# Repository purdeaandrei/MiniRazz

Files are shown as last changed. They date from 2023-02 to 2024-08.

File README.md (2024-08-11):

# MiniRazz - open hardware controller replacement for the Mini M keyboard.

This is a replacement keyboard controller, for the Unicomp Mini M
keyboard, this is an independent community project that is not endorsed by
Unicomp, and it is not related to any official controller sold by them.

Licensed under CERN-OHL-P v2 or later

## Images

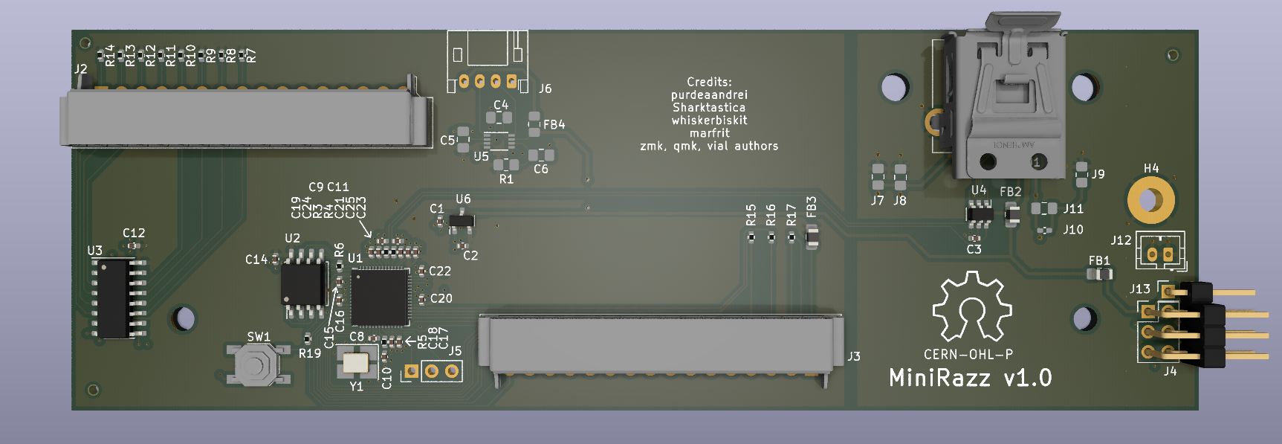
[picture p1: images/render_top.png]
Top of the controller board

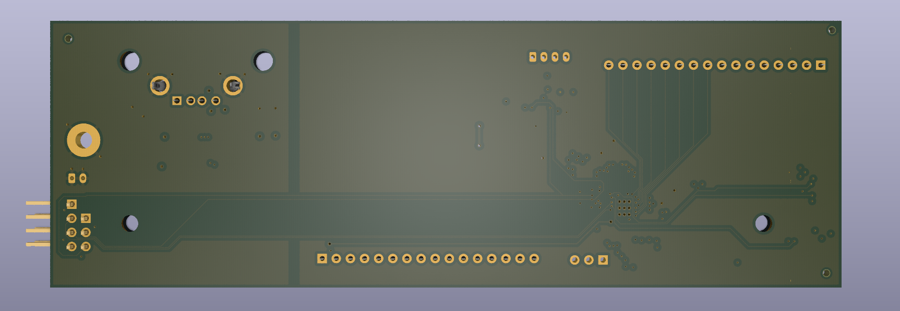
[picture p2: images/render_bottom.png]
Bottom of the controller board


## How to order from JLCPCB:
1. Go to http://jlcpcb.com , sign in to your account (create one if you don't have one)
2. Click Order Now, click Add gerber file
3. Upload the .zip file from the "order" subfolder.
4. Wait for the gerbers to be processed.
5. Check that it correctly detected 4-layerboard.
6. Select PCB Qty you wish to build
7. Specify Layer Sequence, click Yes, And select L1=F_Cu L2=In1_Cu L3=In2_Cu L4=B_Cu
8. Set "Remove Order Number" to "Specify a location"
9. Scroll down, turn on the "SMT Assembly" option, turn it on
10. Select "PCBA Type" = "Economic"
11. Select "Assembly Side" = "Top Side"
12. Select "Tooling holes" = "Added by Customer"
13. Click "I agree to the Terms and Conditions..."
14. Click "Next" on the right side
15. Click "Next" on the right side
16. Click "Add BOM File", upload the "*_bom_jlc.csv" file from the "order" subfolder.
17. Click "Add CPL File", upload the "*_cpl_jlc.csv" file from the "order" subfolder.
18. Click "Process BPM & CPL"
19. Take a look at what parts are available. At the time of writing J2/J3 triomate connectors were only available if pre-ordered (at a higher cost than ordering from DigiKey).
    You may be able to optimize cost by choosing to solder certain parts yourself, through-hole parts being the most likely candidate. (Please see the following section)
20. Click "Next", you will also have to click "Do Not Place" if some components are missing.
21. Check the rotation of components. JLCPCB may change default rotation in their component libraries at any time, and also position and rotation of the triomates has not been verified.
    - Check that component pins line up correctly with pads
    - Check that components which have polarity (usually marked with a dot) are oriented towards an assimetric marking on the silkscreen (for example for the memory and the io expander there's an extra line, while for the RP2040 there's a missing corner line to mark pin 1)
22. Click "Next"
23. Select Product Description: Office Appliance.../Keyboard...
24. Save to Cart, Check Out.

Cost analysis at the time of writing (2024 Aug 11):

| Qty | JLCPCB (USD) | JLC shipping est. (USD) | Digikey Triomates (USD) | Digikey shipping est. (USD) | VAT (19%) USD | Total (USD) | Coast per Board (USD) |
|-----|---|---|---|---|---|---|---|
| 5 | 84.34 | 23.80 | 14.66 | 30 | 29.03 | 181.83 | 36.37 |
| 10  |  106.13 | 29.80 | 29.32 | 30 | 37.10 | 232.35 | 23.24 |
| 15  |  130.10 | 55.54 | 43.76 | 30 | 49.29 | 308.69 | 20.58 |
| 20  |  154.18 | 57.74 | 58.35 | 30 | 57.05 | 357.32 | 17.87 |

## Components of this design that may have to be ordered separately:
- 2 pcs of 16-pin 90-degree triomate connectors / board:
   - Part number: `6-520314-6` (TE Connectivity AMP Connectors)
   - [Digikey](https://www.digikey.com/en/products/detail/te-connectivity-amp-connectors/6-520314-6/1153749)
   - If the 90-degree connectors are not in stock, then you may also be able to get away with vertical ones (part number `6-520315-6`)
      - This has not yet been tested for fit in the keyboard.
   - JLCPCB now has it in its library, however it's not in stock.
     - You can pre-order it, and then have them assemble it, however it may not make financial sense (current costs are higher than from digikey, and you have to order 5 pcs extra for attrition.)
       - If you decide to have JLCPCB assemble this component, it is present in the bom/cpl files, but make sure the connector position/rotations are connect. I could not verify because they weren't in stock at the time I last checked.

## Other through hole components that may make sense to buy separately and to solder yourself:
- USB connector with locking tab
   - Part number: `LUSBA11100` (AMPHENOL COMMUNICATIONS SOLUTIONS)
   - [Digikey](https://www.digikey.com/en/products/detail/amphenol-cs-commercial-products/LUSBA11100/1956311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)
   - [Farnell](https://ro.farnell.com/amphenol-icc-commercial-products/lusba11100/usb-conn-2-0-type-a-receptacle/dp/2708971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)
- Optional 90 degree headers for solenoid support. You can use one of two options:
   - An 1x4 90-degree header: (recommended)
      - You will need to use single jumper wires to connect the solenoid driver, (or need to crimp a custom cable with dupont connectors)
   - A 2x3 90-degree header: (not recommended)
      - This may not fit well in the space available, and you may need to add tape to isolate the bottom of the backplate.

## Firmware

VIAL-QMK and ZMK firmwares are available, (plain QMK upstreaming will also be attempted).

### VIAL Firmware
Download from here:
https://github.com/purdeaandrei/vial-qmk-minirazz/releases

Use `unicomp_mini_m_minirazz_vial.uf2` or `unicomp_mini_m_minirazz_vial_debug.uf2`

### ZMK Firmware
The ZMK firmware can be downloaded by clicking Releases here: https://github.com/purdeaandrei/minirazz-zmk-config
The keymap can be customized by forking this repository, and editing the keymap. The firmware will be automatically rebuilt by github, and will be available on the "Actions" tab.
If you want to keep your keymap secret, you can copy the content of this repository into a private github repository.

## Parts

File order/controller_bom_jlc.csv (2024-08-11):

Comment | Designator | Footprint | LCSC Part Number
1uF | C1,C2,C21,C25 | C_0402_1005Metric | C52923
100nF | C3,C12,C14,C15,C16,C17,C18,C19,C20,C22,C23,C24 | C_0402_1005Metric | C1525
30pF | C8,C10 | C_0402_1005Metric | C1570
43pF | C9,C11 | C_0402_1005Metric | C415393
Ferrite_Bead | FB1,FB2,FB3 | L_0805_2012Metric_Pad1.15x1.40mm_HandSolder | C1015
USB_A | J1 | LUSB_A111_00 | C3197751
Conn_01x16 | J2,J3 | TE_connectivity_AMP_6-520314-6 | C7191217
3.3V IO EXPANSION HEADER | J4 | PinHeader_2x03_P2.54mm_Vertical_3dhorizontal | C706867
27.4 | R3,R4 | R_0402_1005Metric | C284479
1k | R5,R19 | R_0402_1005Metric | C11702
10k | R6 | R_0402_1005Metric | C25744
68k | R7,R8,R9,R10,R11,R12,R13,R14 | R_0402_1005Metric | C36871
196 | R15,R16,R17 | R_0402_1005Metric | C270631
SW_Push | SW1 | switch_K2-1187SQ-A4SW-06 | C92584
RP2040 | U1 | QFN-56-1EP_7x7mm_P0.4mm_EP3.2x3.2mm | C2040
W25Q16JV | U2 | SOIC-8_5.275x5.275mm_P1.27mm | C82317
74HC165 | U3 | SOIC-16_3.9x9.9mm_P1.27mm | C5613
USBLC6-2SC6 | U4 | SOT-23-6 | C2827654
XC6206P332MR | U6 | SOT-23 | C5446
12MHz | Y1 | Crystal_SMD_3225-4Pin_3.2x2.5mm_HandSoldering | C9002

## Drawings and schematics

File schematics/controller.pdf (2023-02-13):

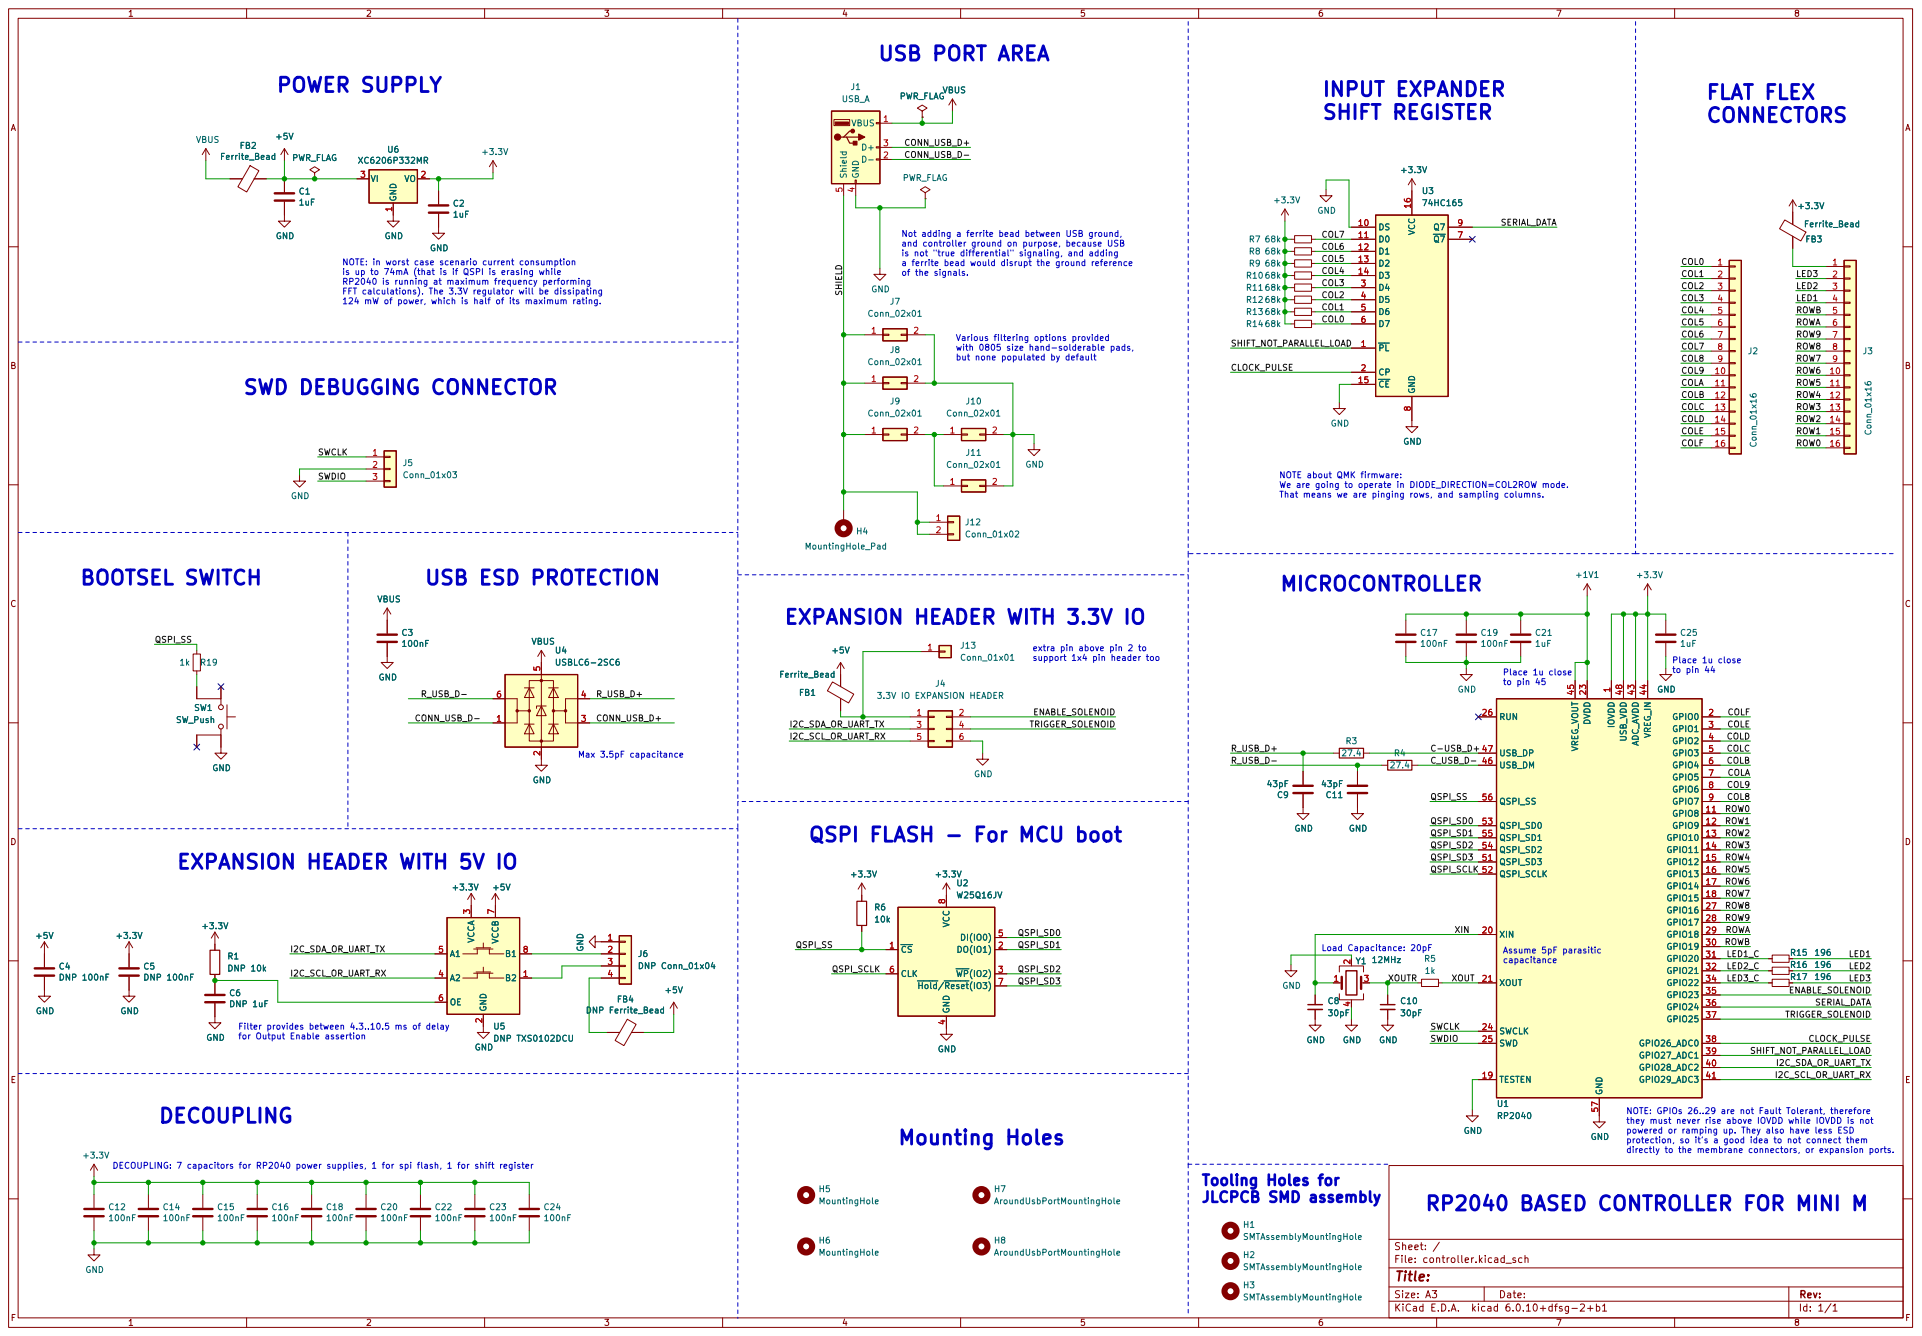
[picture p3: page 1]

1 VO 2 VI 3 U6 XC6206P332MR GND GND
PWR_FLAG

1 VO 2 VI 3 VBUS GND

Not adding a ferrite bead between USB ground,
and controller ground on purpose, because USB
is not "true differential" signaling, and adding
a ferrite bead would disrupt the ground reference
of the signals.
J12 Conn_01x02 GND

NOTE: in worst case scenario current consumption
is up to 74mA (that is if QSPI is erasing while
RP2040 is running at maximum frequency performing
FFT calculations). The 3.3V regulator will be dissipating
124 mW of power, which is half of its maximum rating.

Various filtering options provided
with 0805 size hand-solderable pads,
but none populated by default
GND

to pin 45 NOTE about QMK firmware: We are going to operate in DIODE_DIRECTION=COL2ROW mode.

That means we are pinging rows, and sampling columns.

EXPANSION HEADER WITH 3.3V IO

extra pin above pin 2 to

QSPI FLASH - For MCU boot
H5MountingHole +3.3VR6

EXPANSION HEADER WITH 5V IO

4 DI(IO0) 5 CLK 6 ~{Hold}/~{Reset}(IO3)7 VCC

Filter provides between 4.3..10.5 ms of delay

they must never rise above IOVDD while IOVDD is not
powered or ramping up. They also have less ESD
protection, so it's a good idea to not connect them
directly to the membrane connectors, or expansion ports.

DECOUPLING: 7 capacitors for RP2040 power supplies, 1 for spi flash, 1 for shift register

RP2040 BASED CONTROLLER FOR MINI M

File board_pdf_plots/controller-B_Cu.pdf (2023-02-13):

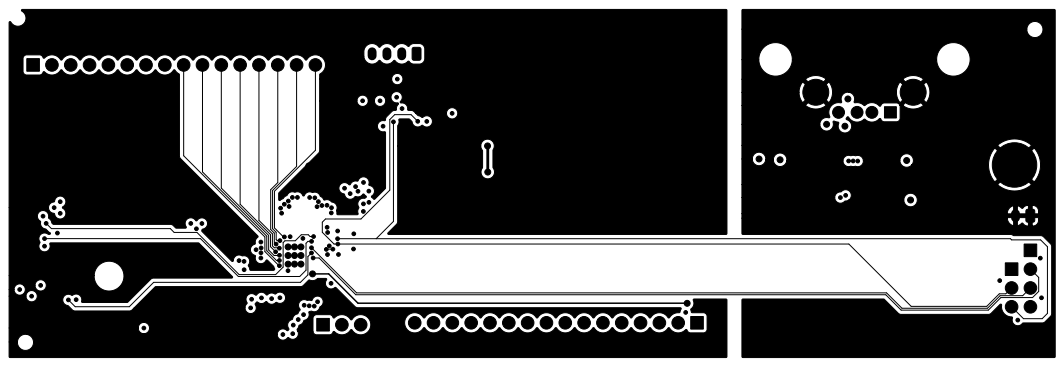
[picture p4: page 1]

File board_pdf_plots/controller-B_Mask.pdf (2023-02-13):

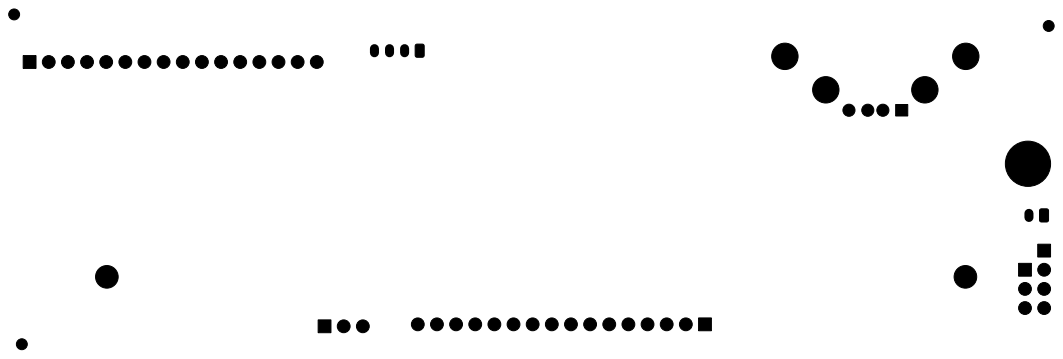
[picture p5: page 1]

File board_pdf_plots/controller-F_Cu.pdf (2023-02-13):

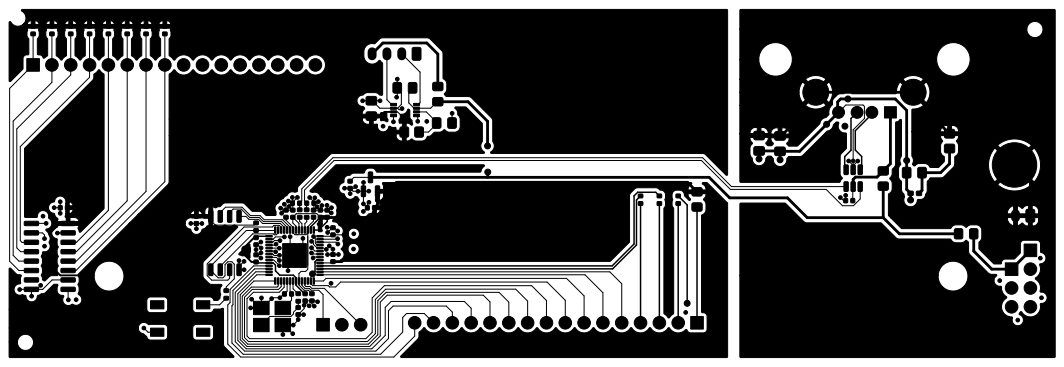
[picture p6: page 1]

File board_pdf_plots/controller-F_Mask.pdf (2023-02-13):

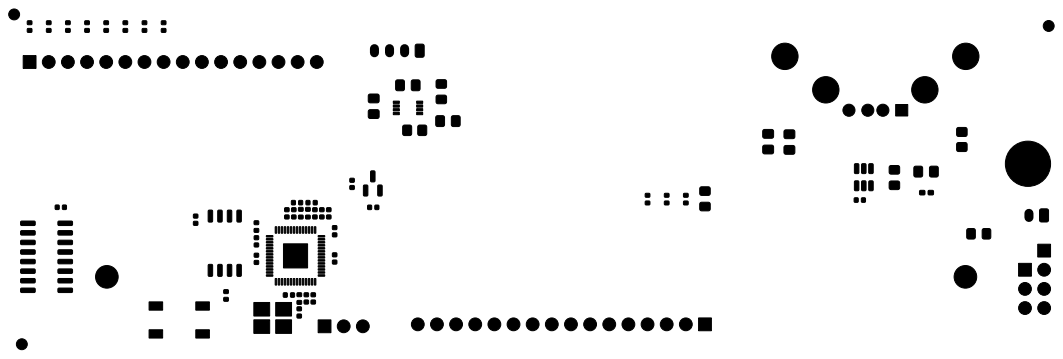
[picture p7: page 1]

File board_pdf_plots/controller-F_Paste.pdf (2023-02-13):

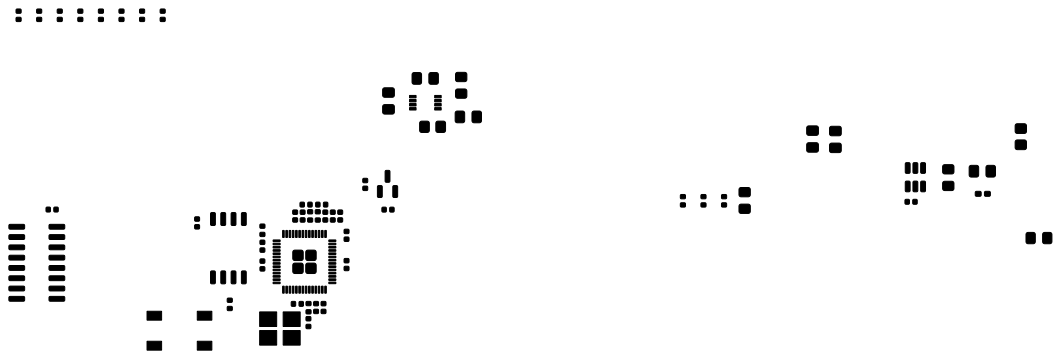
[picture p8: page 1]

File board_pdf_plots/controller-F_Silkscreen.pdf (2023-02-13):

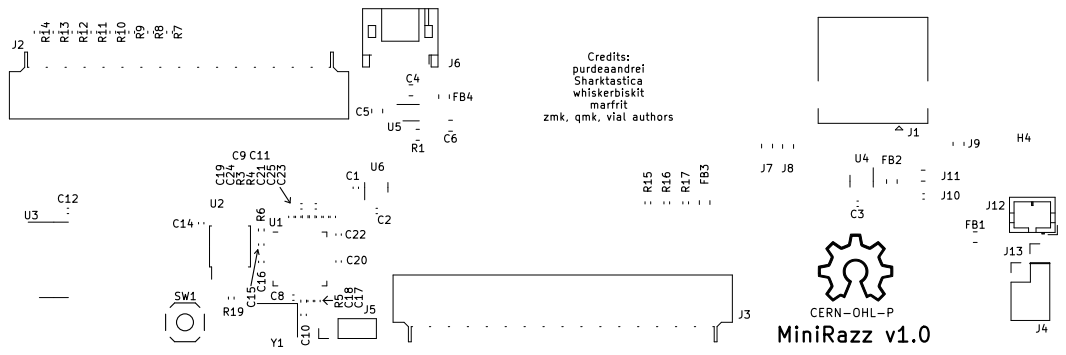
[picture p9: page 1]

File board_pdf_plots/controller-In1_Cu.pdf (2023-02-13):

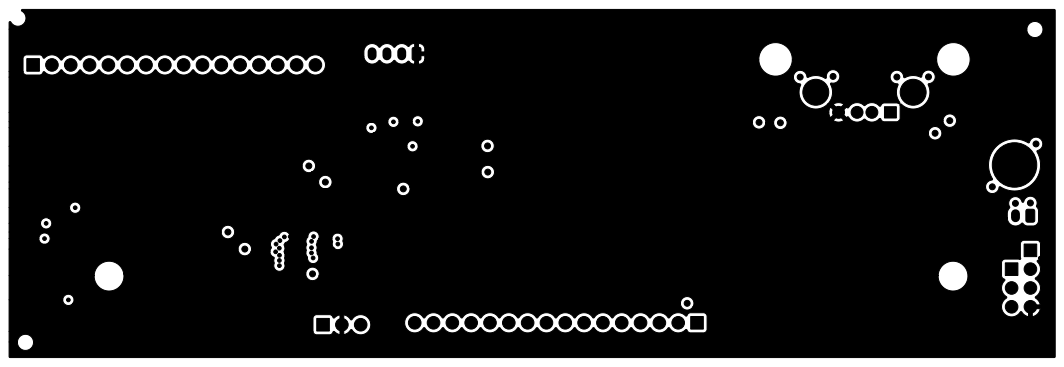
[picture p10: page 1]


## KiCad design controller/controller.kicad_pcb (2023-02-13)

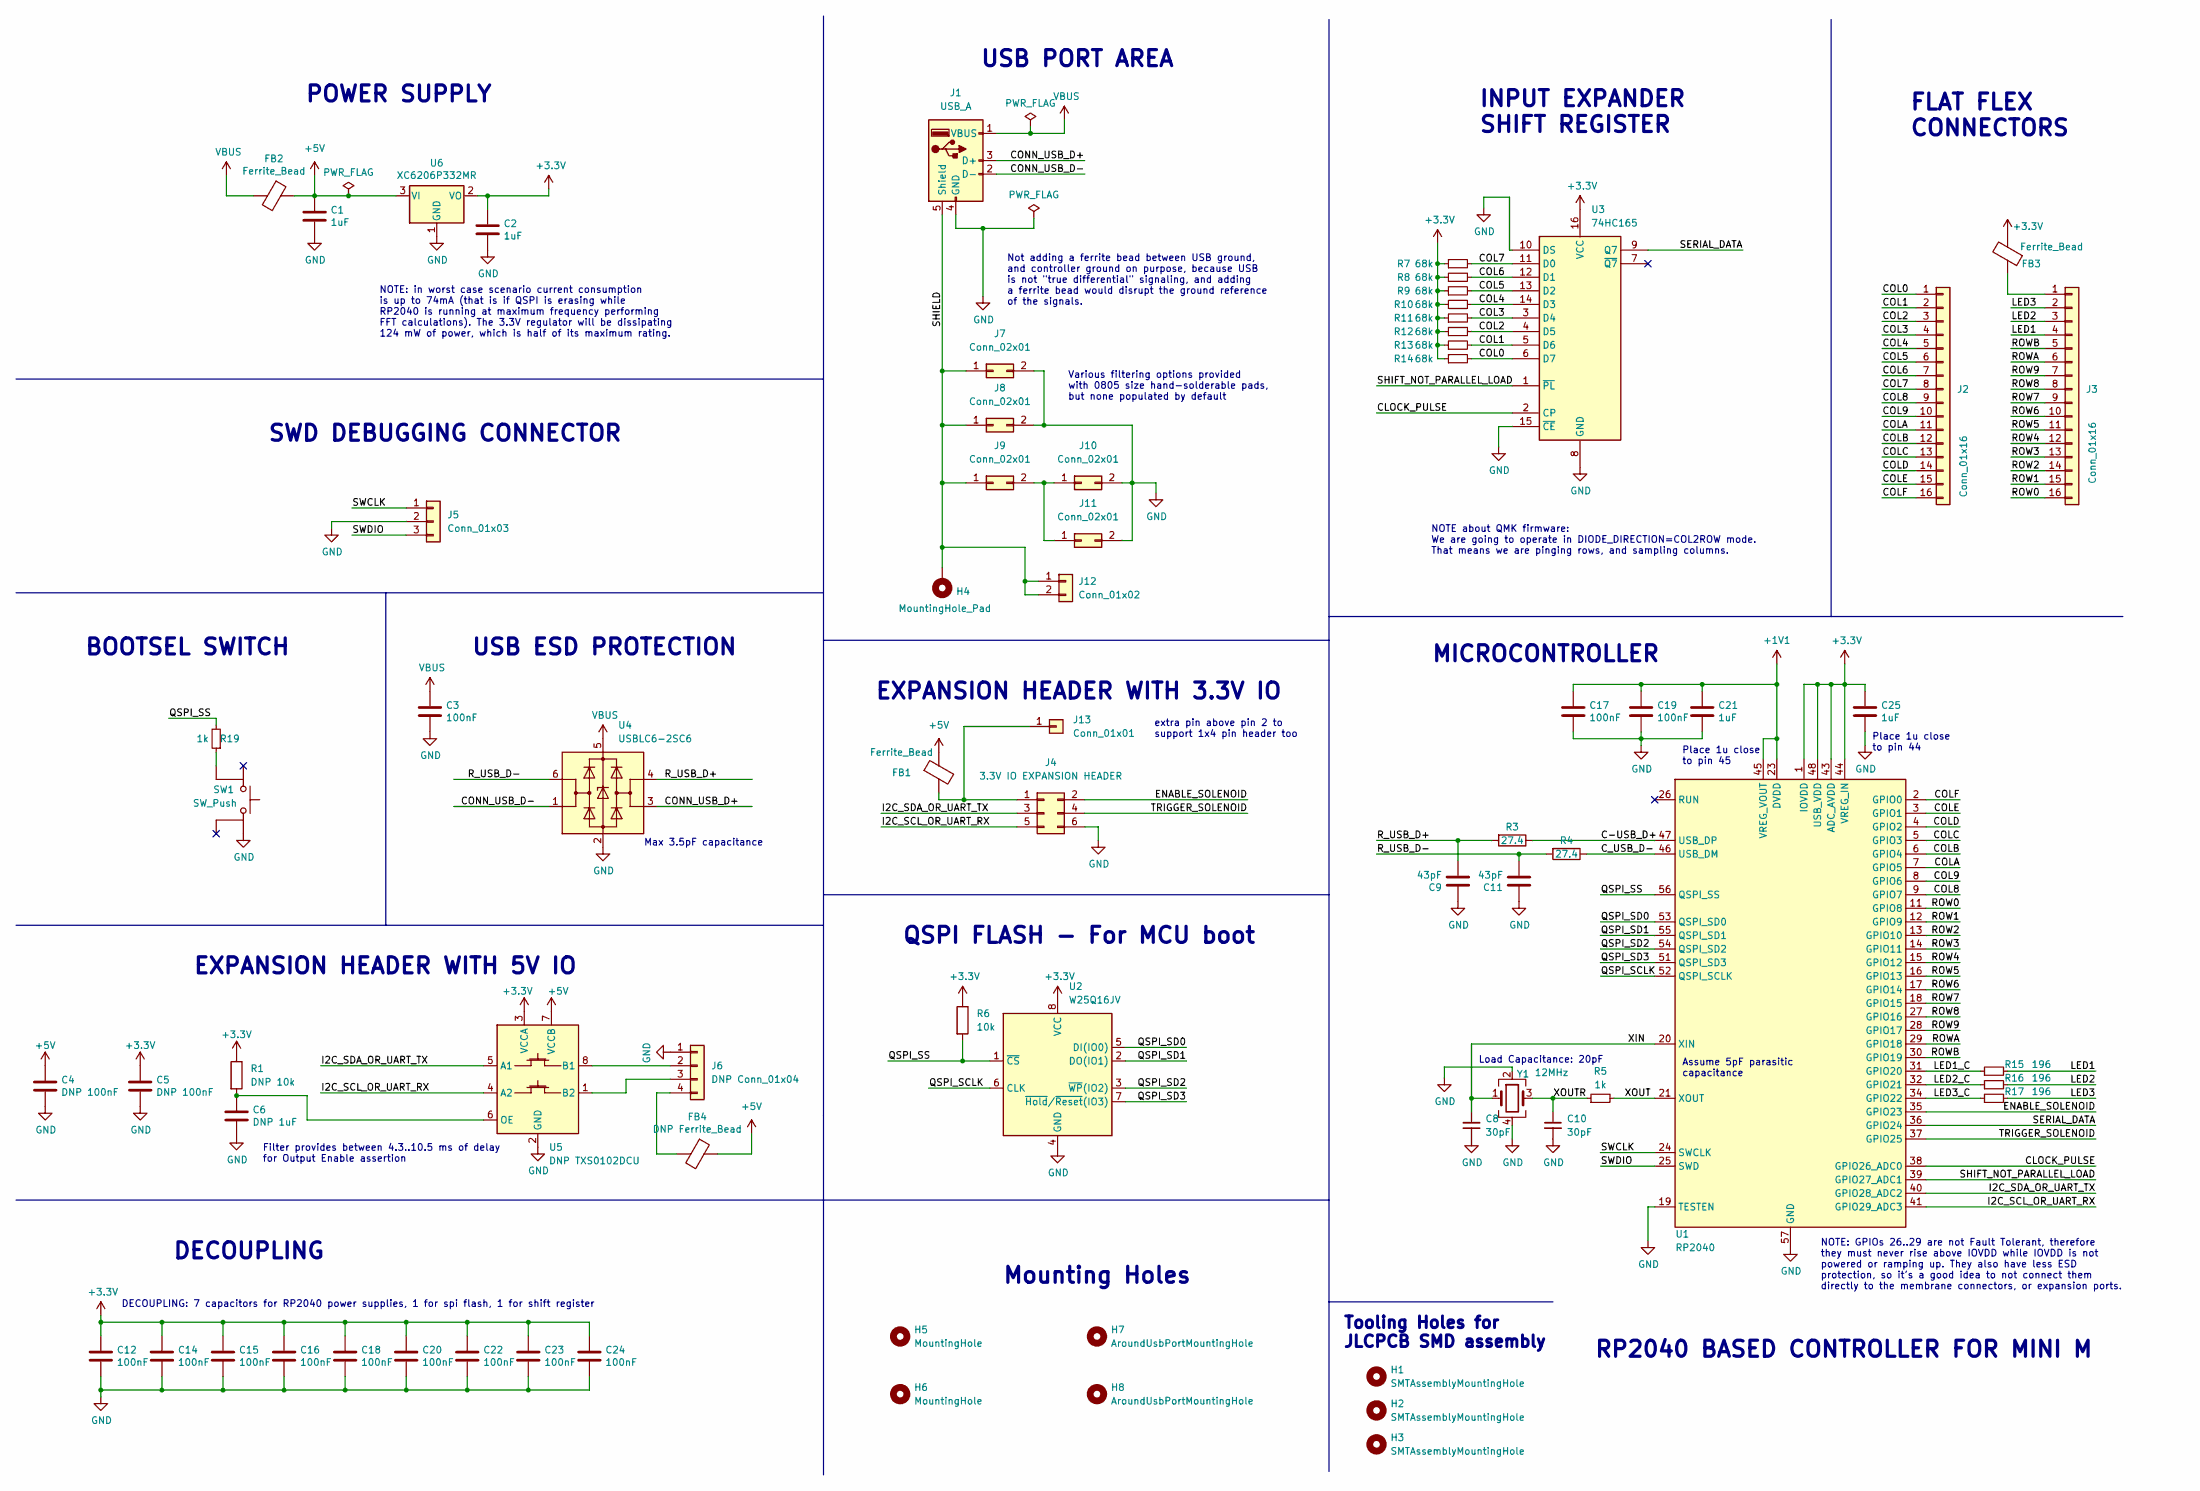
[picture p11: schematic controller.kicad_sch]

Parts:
C1, C2, C21, C25: 1uF; C_0402_1005Metric; LCSC C52923
C3, C12, C14, C15, C16, C17, C18, C19, C20, C22, C23, C24: 100nF; C_0402_1005Metric; LCSC C1525
C4, C5: DNP 100nF; C_0805_2012Metric_Pad1.18x1.45mm_HandSolder
C6: DNP 1uF; C_0805_2012Metric_Pad1.18x1.45mm_HandSolder
C8, C10: 30pF; C_0402_1005Metric; LCSC C1570
C9, C11: 43pF; C_0402_1005Metric; LCSC C415393
FB1, FB2, FB3: Ferrite_Bead; L_0805_2012Metric_Pad1.15x1.40mm_HandSolder; LCSC C1015
FB4: DNP Ferrite_Bead; L_0805_2012Metric_Pad1.15x1.40mm_HandSolder; LCSC C1015
H1, H2, H3: SMTAssemblyMountingHole; tooling_hole
H4: MountingHole_Pad; MountingHole_3mm_Pad
H5, H6: MountingHole; MountingHole_3mm
H7, H8: AroundUsbPortMountingHole; MountingHole_3.5mm
J1: USB_A; LUSB_A111_00
J2, J3: Conn_01x16; TE_connectivity_AMP_6-520314-6
J4: 3.3V IO EXPANSION HEADER; PinHeader_2x03_P2.54mm_Vertical_3dhorizontal
J5: Conn_01x03; PinHeader_1x03_P2.54mm_Vertical
J6: DNP Conn_01x04; JST_PH_S4B-PH-K_1x04_P2.00mm_Horizontal
J7, J8, J11: Conn_02x01; C_0805_2012Metric_Pad1.18x1.45mm_HandSolder
J9: Conn_02x01; R_0805_2012Metric_Pad1.20x1.40mm_HandSolder
J10: Conn_02x01; C_0402_1005Metric_Pad0.74x0.62mm_HandSolder
J12: Conn_01x02; JST_PH_B2B-PH-K_1x02_P2.00mm_Vertical
J13: Conn_01x01; PinHeader_1x01_P2.54mm_Vertical_3dhorizontal
R1: DNP 10k; R_0805_2012Metric_Pad1.20x1.40mm_HandSolder; LCSC C25744
R3, R4: 27.4; R_0402_1005Metric; LCSC C284479
R5, R19: 1k; R_0402_1005Metric; LCSC C11702
R6: 10k; R_0402_1005Metric; LCSC C25744
R7, R8, R9, R10, R11, R12, R13, R14: 68k; R_0402_1005Metric; LCSC C36871
R15, R16, R17: 196; R_0402_1005Metric; LCSC C270631
SW1: SW_Push; switch_K2-1187SQ-A4SW-06; LCSC C92584
U1: RP2040; QFN-56-1EP_7x7mm_P0.4mm_EP3.2x3.2mm; LCSC C2040
U2: W25Q16JV; SOIC-8_5.275x5.275mm_P1.27mm; LCSC C82317
U3: 74HC165; SOIC-16_3.9x9.9mm_P1.27mm; LCSC C5613
U4: USBLC6-2SC6; SOT-23-6; LCSC C2827654
U5: DNP TXS0102DCU; VSSOP-8_2.3x2mm_P0.5mm
U6: XC6206P332MR; SOT-23; LCSC C5446
Y1: 12MHz; Crystal_SMD_3225-4Pin_3.2x2.5mm_HandSoldering; LCSC C9002

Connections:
+1V1: C17.1, C19.1, C21.1, U1.23 (DVDD), U1.45 (VREG_VOUT), U1.50 (DVDD)
+3.3V: C2.1, C5.1, C12.1, C14.1, C15.1, C16.1, C18.1, C20.1, C22.1, C23.1, C24.1, C25.1, FB3.2, R1.1, R6.1, R7.1, R8.1, R9.1, R10.1, R11.1, R12.1, R13.1, R14.1, U1.1 (IOVDD), U1.10 (IOVDD), U1.22 (IOVDD), U1.33 (IOVDD), U1.42 (IOVDD), U1.43 (ADC_AVDD), U1.44 (VREG_IN), U1.48 (USB_VDD), U1.49 (IOVDD), U2.8 (VCC), U3.16 (VCC), U5.3 (VCCA), U6.2 (VO)
/C-USB_D+: R3.1, U1.47 (USB_DP)
/CLOCK_PULSE: U1.38 (GPIO26_ADC0), U3.2 (CP)
/COL0: J2.1, R14.2, U3.6 (D7)
/COL1: J2.2, R13.2, U3.5 (D6)
/COL2: J2.3, R12.2, U3.4 (D5)
/COL3: J2.4, R11.2, U3.3 (D4)
/COL4: J2.5, R10.2, U3.14 (D3)
/COL5: J2.6, R9.2, U3.13 (D2)
/COL6: J2.7, R8.2, U3.12 (D1)
/COL7: J2.8, R7.2, U3.11 (D0)
/COL8: J2.9, U1.9 (GPIO7)
/COL9: J2.10, U1.8 (GPIO6)
/COLA: J2.11, U1.7 (GPIO5)
/COLB: J2.12, U1.6 (GPIO4)
/COLC: J2.13, U1.5 (GPIO3)
/COLD: J2.14, U1.4 (GPIO2)
/COLE: J2.15, U1.3 (GPIO1)
/COLF: J2.16, U1.2 (GPIO0)
/CONN_USB_D+: J1.3 (D+), U4.3 (I/O2)
/CONN_USB_D-: J1.2 (D-), U4.1 (I/O1)
/C_USB_D-: R4.1, U1.46 (USB_DM)
/ENABLE_SOLENOID: J4.2, U1.35 (GPIO23)
/I2C_SCL_OR_UART_RX: J4.5, U1.41 (GPIO29_ADC3), U5.4 (A2)
/I2C_SDA_OR_UART_TX: J4.3, U1.40 (GPIO28_ADC2), U5.5 (A1)
/LED1: J3.4, R15.2
/LED1_C: R15.1, U1.31 (GPIO20)
/LED2: J3.3, R16.2
/LED2_C: R16.1, U1.32 (GPIO21)
/LED3: J3.2, R17.2
/LED3_C: R17.1, U1.34 (GPIO22)
/QSPI_SCLK: U1.52 (QSPI_SCLK), U2.6 (CLK)
/QSPI_SD0: U1.53 (QSPI_SD0), U2.5 (DI(IO0))
/QSPI_SD1: U1.55 (QSPI_SD1), U2.2 (DO(IO1))
/QSPI_SD2: U1.54 (QSPI_SD2), U2.3 (~WP(IO2))
/QSPI_SD3: U1.51 (QSPI_SD3), U2.7 (~Hold/~Reset(IO3))
/QSPI_SS: R6.2, R19.2, U1.56 (QSPI_SS), U2.1 (~CS)
/ROW0: J3.16, U1.11 (GPIO8)
/ROW1: J3.15, U1.12 (GPIO9)
/ROW2: J3.14, U1.13 (GPIO10)
/ROW3: J3.13, U1.14 (GPIO11)
/ROW4: J3.12, U1.15 (GPIO12)
/ROW5: J3.11, U1.16 (GPIO13)
/ROW6: J3.10, U1.17 (GPIO14)
/ROW7: J3.9, U1.18 (GPIO15)
/ROW8: J3.8, U1.27 (GPIO16)
/ROW9: J3.7, U1.28 (GPIO17)
/ROWA: J3.6, U1.29 (GPIO18)
/ROWB: J3.5, U1.30 (GPIO19)
/R_USB_D+: C9.2, R3.2, U4.4 (I/O2)
/R_USB_D-: C11.2, R4.2, U4.6 (I/O1)
/SERIAL_DATA: U1.36 (GPIO24), U3.9 (Q7)
/SHIELD: H4.1, J1.5 (Shield), J7.1, J8.1, J9.1, J12.1, J12.2
/SHIFT_NOT_PARALLEL_LOAD: U1.39 (GPIO27_ADC1), U3.1 (~PL)
/SWCLK: J5.1, U1.24 (SWCLK)
/SWDIO: J5.3, U1.25 (SWD)
/TRIGGER_SOLENOID: J4.4, U1.37 (GPIO25)
/XIN: C8.1, U1.20 (XIN), Y1.1
/XOUT: R5.2, U1.21 (XOUT)
/XOUTR: C10.1, R5.1, Y1.3
unnamed: C6.1, R1.2, U5.6 (OE)
unnamed: FB1.2, J4.1, J13.1
unnamed: FB3.1, J3.1
unnamed: FB4.2, J6.4
unnamed: J6.2, U5.8 (B1)
unnamed: J6.3, U5.1 (B2)
unnamed: J9.2, J10.1, J11.1
unnamed: R19.1, SW1.2

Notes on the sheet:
DECOUPLING: 7 capacitors for RP2040 power supplies, 1 for spi flash, 1 for shift register
USB PORT AREA
Tooling Holes for JLCPCB SMD assembly
Place 1u close to pin 45
Max 3.5pF capacitance
Place 1u close to pin 44
FLAT FLEX CONNECTORS
Not adding a ferrite bead between USB ground, and controller ground on purpose, because USB is not "true differential" signaling, and adding a ferrite bead would disrupt the ground reference of the signals.
Various filtering options provided with 0805 size hand-solderable pads, but none populated by default
EXPANSION HEADER WITH 5V IO
NOTE: GPIOs 26..29 are not Fault Tolerant, therefore they must never rise above IOVDD while IOVDD is not powered or ramping up. They also have less ESD protection, so it's a good idea to not connect them directly to the membrane connectors, or expansion ports.
Load Capacitance: 20pF
USB ESD PROTECTION
QSPI FLASH - For MCU boot
RP2040 BASED CONTROLLER FOR MINI M
extra pin above pin 2 to support 1x4 pin header too
Mounting Holes
BOOTSEL SWITCH
DECOUPLING
EXPANSION HEADER WITH 3.3V IO
NOTE: in worst case scenario current consumption is up to 74mA (that is if QSPI is erasing while RP2040 is running at maximum frequency performing FFT calculations). The 3.3V regulator will be dissipating 124 mW of power, which is half of its maximum rating.
Filter provides between 4.3..10.5 ms of delay for Output Enable assertion
POWER SUPPLY
MICROCONTROLLER
NOTE about QMK firmware: We are going to operate in DIODE_DIRECTION=COL2ROW mode. That means we are pinging rows, and sampling columns.
SWD DEBUGGING CONNECTOR
INPUT EXPANDER SHIFT REGISTER
Assume 5pF parasitic capacitance

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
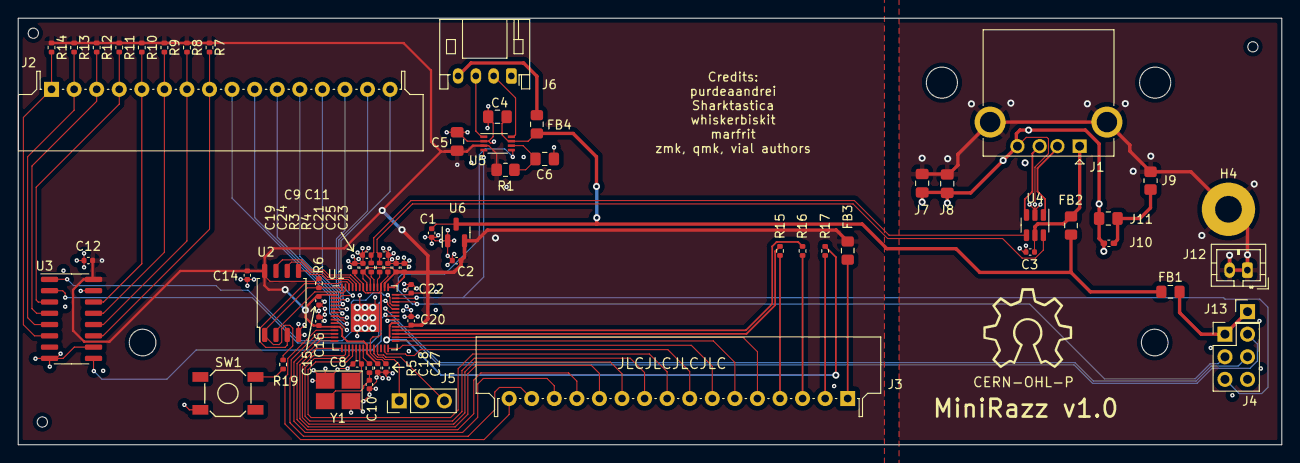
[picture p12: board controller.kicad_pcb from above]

Board: 4 copper layers, 142.2 x 48.0 mm, 73 parts (0 on the bottom side), 72 nets.

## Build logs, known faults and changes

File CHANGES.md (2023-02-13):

# v1.0
 - Silkscreen added with project name, version, credits, etc...
 - Some unused footprints removed
 - Changed BOM of R3, R4, from C25100 to C284479, because it was out of stock.

# Prototype
 - Initial prototype, only 10 pcs ever built
 - No identifying silkscreen markings
 - Worked out of the box, no bodges necessary.

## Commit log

2023-02-13 added digikey link to usb connector
2024-08-11 Added LCSC part numbers for through-hole components
    [controller.kicad_sch, controller_bom_jlc.csv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]
